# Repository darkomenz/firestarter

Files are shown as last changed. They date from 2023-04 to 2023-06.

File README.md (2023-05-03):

# Hexastorm PCB
This repository provides two modules;
 * **Laser module**  
    Contains six PCBs for the laser head. A box is created by the PCBs.  
    A baseboard, a front and back plate, a side plate and a top plate.  
    The laser module is standalone and can be controlled via SPI.  
 * **Main board**  
    The main board can be used to control motors and the laser head.  
    It's very basic and just serves as an example on how to control the laser head.   
    
A blog with progress updates is available on [Hackaday](https://hackaday.io/project/21933-open-hardware-fast-high-resolution-laser). 

# Status
Several systems were designed. A successful exposure is shown in this [video](https://youtu.be/dR09Tev0cPk).  
The current system is going through a complete iteration. Older versions of the laser head can be found in
the old branch of this repo.    
A presentation on the current target is found [here](https://youtu.be/b7ArZDhsyfI).  
Goals are;
  - improve documentation
  - make the laser module standalone

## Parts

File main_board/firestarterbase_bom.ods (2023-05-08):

Price | Qty | RefDes | Producer Part No | Producer | Farnell Part No | Mouser | DigiKey Part No | Description
1,63 | 1 |  | Wurth | 61304021821 | 2827916 |  |  | 40 pin connector
5,13 | 1 | U1 | ICE40UP5K-SG48I | Lattice |  | 842-ICE40UP5K-SG48I |  | ICE40UP5K FPGA, only mouser
0,752 | 2 | J1, J2 | 1-1734248-5 | TE Connectivity | 2890893 |  |  | connectors to scanhead and motor board
0,152 | 1 | D2 | CLMVC-FKA-CLBDGL7LBB79353 | Cree LED |  | 941-CLMVCFKACLBDGL7L |  | Color led
1,16 | 1 | J4 | MKDS 1,5/2 | Phoenix Contact | 3714240 |  |  | power connector
0,545 | 1 | U2 | MCP1700T-1202E/TT | Microchip | 1851940 |  |  | voltage supply 200 mA
0,745 | 1 | U5 | W25Q32JVSSIM | Winbond |  | 454-W25Q32JVSSIM |  | flash ram, Farnell alternative Is S25FL064LABMFI010
0,52 | 1 | Y1 | X1G0041710023 SG-210STF 13.56MHZ L | Epson | 2405713 |  |  | Oscillator, 2.5x2 mm 4 pins SMD, standaard formaat oscillators gaan snel uit vooruit
 | 1 |  | VISHAY | CRCW0805100RFKE | 1469862 (https://nl.farnell.com/vishay/crcw0805100rfkea/res-100r-1-0-125w-0805-thick-film/dp/1469862) |  |  | 100 ohm resistor
 | 4 |  | VISHAY | CRCW080510K0FKEA | 1469856 (https://nl.farnell.com/vishay/crcw080510k0fkea/res-10k-1-0-125w-0805-thick-film/dp/1469856) |  |  | 10K resistor
 | 5 |  | MULTICOMP | MC0805B104K101CT | 2320821 (https://nl.farnell.com/multicomp/mc0805b104k101ct/cap-0-1-f-100v-10-x7r-0805/dp/2320821) |  |  | 0.1 u cap (0.1 microfarad)
0,0906 | 5 |  | YAGEO | CC0805ZRY5V6BB475 | 3369339 (https://nl.farnell.com/yageo/cc0805zry5v6bb475/cap-4-7uf-10v-mlcc-0805/dp/3369339) |  |  | 4.7 u cap (4.7 microfarad)
0,401 | 2 | D8, D1 | ONSEMI | S1A | 9843868 (https://nl.farnell.com/fairchild-semiconductor/s1a/diode-standard-1a-50v-smd/dp/9843868) |  |  | diode
0,247 | 1 | F3 | Bel FUSE – Circuit protection | 0685T3000-01 | 2834856 (https://nl.farnell.com/bel-fuse-circuit-protection/0685t3000-01/fuse-smd-3a-slow-blow-1206/dp/2834856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) |  |  | fuse
Total | 12,888
Note
 |  |  | 691709710302 |  |  |  |  | 2 terminal block surface mount
1,94 | 1 | P1 | 95157-140LF | Amphenol ICC | 2751390 |  |  | WRONG NOT USED AS you need female, surface mount not used as it requires additional stencil and step!

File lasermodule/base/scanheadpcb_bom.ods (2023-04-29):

Price | Qty | RefDes | Producer | Producer Part No | Farnell Part No | Description
0,387 | 1 |  | Harwin | M20-9991045 | 1022259 | 2.54 header pin polygon motor, laserdiode, fan, power
0,616 | 2 | J3, J5 | Molex | 200528-0040 | 3500399 | photodiode 2x
0,453 | 1 | J2 | Amphenol ICC | SFW15R-2STE1LF | 2890893 | FFC / FPC Board Connector, 1 mm, 15 Contacts, Receptacle, FCI 58RF SFW-R series, Surface Mount
1,6 | 1 | U1 | MAXIM | MAX5395MATA+T | 2763348 (https://nl.farnell.com/maxim-integrated-products/max5395mata-t/digital-pot-volatile-50-k-tdfn/dp/2763348) | Digipot 50 kohm
0,0883 | 3 | R1, R2, R3, R4 | VISHAY | CRCW080510K0FKEA | 1469856 (https://nl.farnell.com/vishay/crcw080510k0fkea/res-10k-1-0-125w-0805-thick-film/dp/1469856) | resistor 10 Kohm
0,128 | 1 | C4 | MULTICOMP | MC0805B104K101CT | 2320821 (https://nl.farnell.com/multicomp/mc0805b104k101ct/cap-0-1-f-100v-10-x7r-0805/dp/2320821) | 0.1 µF 2012 cap
0,0725 | 1 | C1 | AVX | 08055C472KAT2A | 499213 (https://nl.farnell.com/avx/08055c472kat2a/cap-4700pf-50v-10-x7r-0805/dp/499213) | 47 nF 2012 cap
0,28 | 2 | C2, C3, C5, C6, C7 | AVX | 08055C105KAT2A | 2094043 (https://nl.farnell.com/avx/08055c105kat2a/cap-1-f-50v-10-x7r-0805/dp/2094043) | 1 µF 2012 cap
7 | 1 | U2 | IC HOUSE | IC-HKB-S08-TP |  | laserdriver only sold via resellers (AVE)
0,714 | 1 | Q1 | INFINEON | IRFML8244TRPBF | 1857298 (http://www.farnell.com/datasheets/1911843.pdf) | MOSFET fan
0,105 | 1 | D1 | ON SEMICONDUCTOR | S1A | 9843868 (https://nl.farnell.com/fairchild-semiconductor/s1a/diode-standard-1a-50v-smd/dp/9843868) | flyback diode fan
1,53 | 1 | U3 | ON SEMICONDUCTOR | NCD98010XMXTAG | 3463948 | ADC converter SPI
1,14 | 3 | F1, F2, F3 | Bel Fuse – Circuit Protection | 0685T3000-01 | 2834856
2,19 | 1 |  | ABL Heatsinks | BGA-STD-015 | 2084425 | heatsink laser diode driver
0,248 | 1 | J1 | Molex | 22-23-2031 | 1462950 | power connector
Total | 19,9044
Cables
0,95 | 1 |  |  | Link (https://elektronicavoorjou.nl/product/jumper-wire-5-pins-10cm/) |  | Jumper wire 5 pin Mirror motor connect
0,95 | 2 |  |  | Link (https://elektronicavoorjou.nl/product/jumper-wire-2-pins-10cm/) |  | Jumper wire 2 pin Laserdiode + Fan
 |  |  |  |  |  | Molex cable for power, crimp, connector
1,03 | 1 |  |  | MP-FFCA10041003A | 3385294 | FFC 4P aansluiting 2 photodiodes
4 | 1 |  |  | Link (https://www.tinytronics.nl/shop/nl/kabels-en-connectoren/kabels-en-adapters/ffc/raspberry-pi-camerakabel-15-pin-fpc-flex-100cm) | 3527203 | FFC 15P data cable 1 meter, cheap as it compatible raspberry
Panasonic Motor connector
Connector |  |  | TE Connectivity AMP Connectors | 292171-5 | A98794-ND
header |  |  | TE Connectivity | 6-173977-5 | 571-6-173977-5
cable clamp |  |  | TE Connectivity | 179227-4 | 571-179227-4
NBC3111 Motor connector |  |  |  |  |  | Original for sharp AR160 161 200 168 1818 158 2820 2718 Polygon Mirror Motor, store name Printer Accessories Store, brand name : HLKTKT
connector |  |  | TE Connectivity AMP Connectors | 292173-5 |  | connector present on board
insert |  |  |  | 179228-5 |  | amp termination for inserts
wire insert for insert |  |  |  | 179227-1 |  | contact end wire depends on AWG
clamp for wire insert for insert |  |  |  | 2305570-1 |  | crimp tool

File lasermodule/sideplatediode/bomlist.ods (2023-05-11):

Price | Qty | RefDes | Producer Part No | Farnell Part | Description
0,0177 | 3 | R1, R3, R6 | CRCW080522K0FKEA | 1469896 (https://nl.farnell.com/vishay/crcw080522k0fkea/res-22k-1-0-125w-0805-thick-film/dp/1469896?st=CRCW080522K0FKEA) | smd resisitor
0,0094 | 5 | R2, R4, R5, R7, R8 | MCWR08X8201FTL | 2447732 (https://nl.farnell.com/multicomp/mcwr08x8201ftl/res-8k2-1-0-125w-thick-film/dp/2447732) | smd resisitor
0,08 | 1 | R7 | CRCW12061K50FKEAHP | 1739015 (http://www.farnell.com/datasheets/2618455.pdf) | smd resisitor
0,413 | 2 | U1, U2 |  | 2920854 (https://nl.farnell.com/microchip/mic920yc5-tr/opamp-80mhz-40-to-85deg-c/dp/2920854) | operational amplifier
1,59 | 1 | D1 | SFH 2440 | 2981709 | photodiode
0,279 | 1 | C3 | 08055C105KAT2A | 2094043 (http://www.farnell.com/datasheets/2237835.pdf) | 1 µF 2012 cap buffer, not sure if 2 are needed copied from previous board
0,0759 | 1 | C1 | MC0805B221K500CT | 1759208 (https://nl.farnell.com/multicomp/mc0805b221k500ct/cap-220pf-50v-10-x7r-0805/dp/1759208) | 220 pF 2012 cap used in opamp
0,616 | 1 | J1 | 200528-0040 | 3500399 | photodiode connector
Total | 3,567
Alternative photodiode
BPW 34 BS-Z
 |  |  | 929974-01-36-RK | 2064805 | 36 way THH connector 2.54 mm

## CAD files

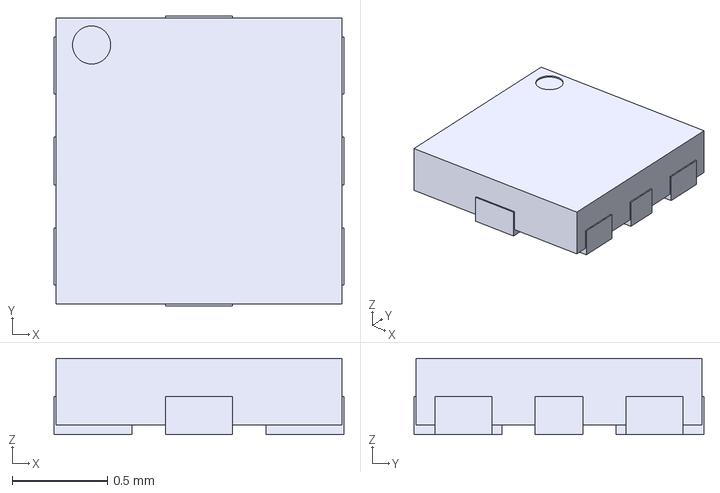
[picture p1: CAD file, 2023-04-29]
lasermodule/base/comp/eec.models/Texas_Instruments_-_ADS7040IRUGR.step
1.52 x 1.52 x 0.4 mm

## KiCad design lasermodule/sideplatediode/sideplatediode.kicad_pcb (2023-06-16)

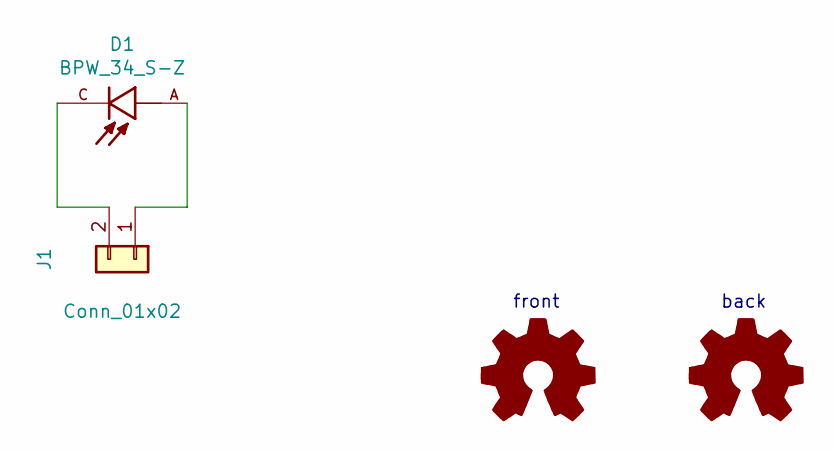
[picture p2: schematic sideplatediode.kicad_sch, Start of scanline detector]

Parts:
D1: BPW_34_S-Z; DIO_BPW_34_S-Z; PARTREV 1.5
J1: Conn_01x02; PinHeader_1x02_P2.54mm_Horizontal
L1, L2: Logo_Open_Hardware_Small; hexastorm

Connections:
unnamed: D1.A, J1.1
unnamed: D1.C, J1.2

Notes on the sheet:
back
front

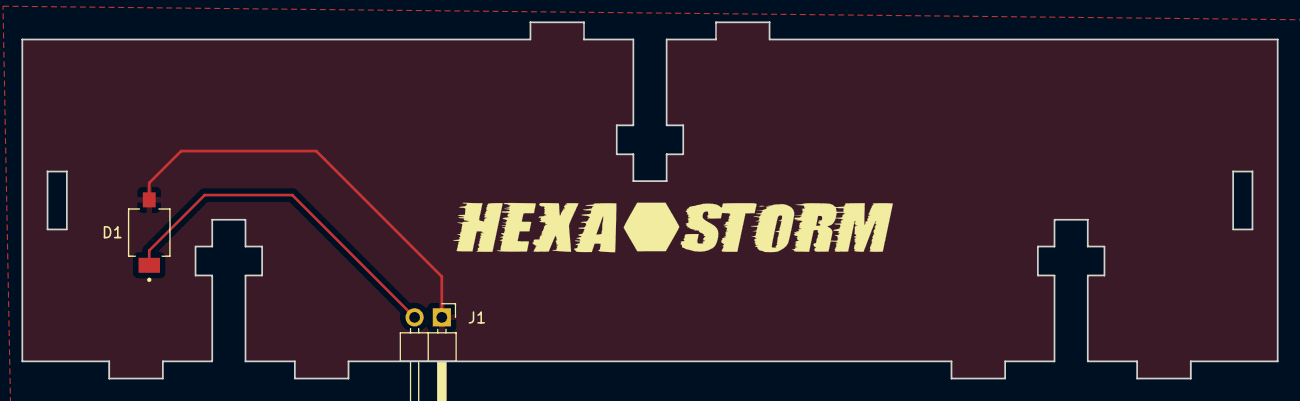
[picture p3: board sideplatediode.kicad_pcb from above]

Board: 2 copper layers, 117.0 x 33.2 mm, 4 parts (1 on the bottom side), 2 nets.

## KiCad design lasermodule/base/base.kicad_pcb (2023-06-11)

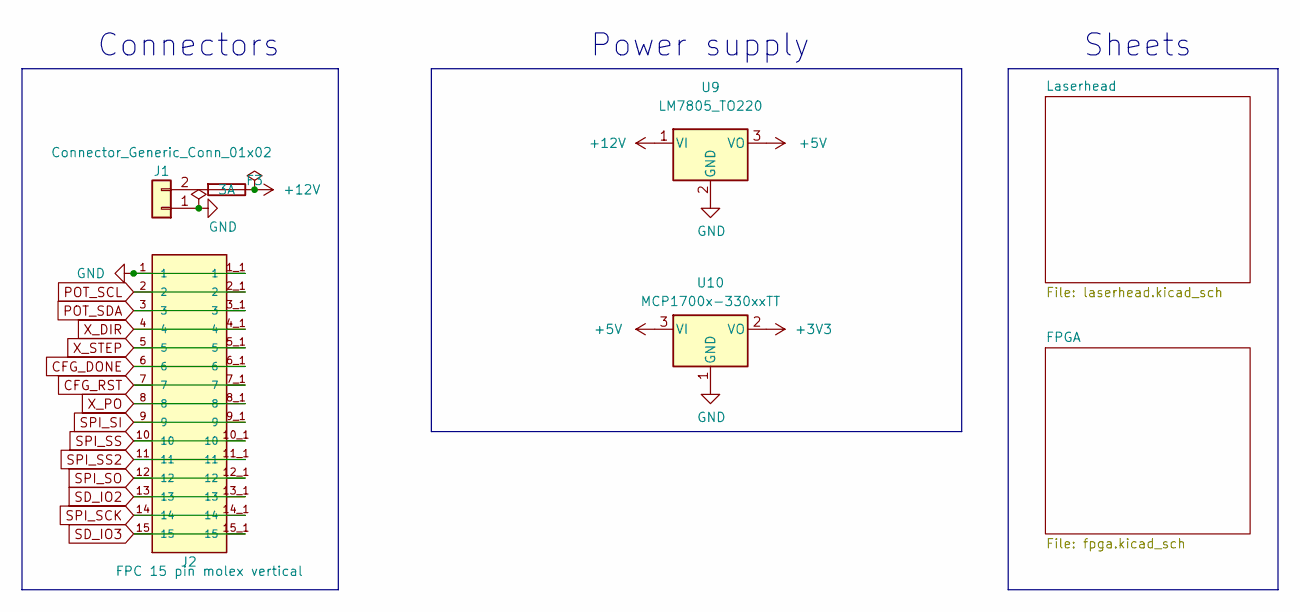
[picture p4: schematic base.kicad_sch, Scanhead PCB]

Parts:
F3: 3A; Fuse_1206_3216Metric
J1: Connector_Generic_Conn_01x02; AMASS_XT30PW-F_1x02_P2.50mm_Horizontal
J2: FPC 15 pin molex vertical; TE_1-1734248-5; PARTREV E1
U9: LM7805_TO220; TO-220-3_Vertical
U10: MCP1700x-330xxTT; SOT-23

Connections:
+3V3: U10.2 (VO); also elsewhere on the board
+5V: U9.3 (VO), U10.3 (VI); also elsewhere on the board
+12V: F3.1, U9.1 (VI); also elsewhere on the board
CFG_DONE: J2.6, J2.6_1 (6); also elsewhere on the board
CFG_RST: J2.7, J2.7_1 (7); also elsewhere on the board
GND: J1.1, J2.1, J2.1_1 (1), U9.2 (GND), U10.1 (GND); also elsewhere on the board
unnamed: F3.2, J1.2
POT_SCL: J2.2, J2.2_1 (2); also elsewhere on the board
POT_SDA: J2.3, J2.3_1 (3); also elsewhere on the board
SD_IO2: J2.13, J2.13_1 (13); also elsewhere on the board
SD_IO3: J2.15, J2.15_1 (15); also elsewhere on the board
SPI_SCK: J2.14, J2.14_1 (14); also elsewhere on the board
SPI_SI: J2.9, J2.9_1 (9); also elsewhere on the board
SPI_SO: J2.12, J2.12_1 (12); also elsewhere on the board
SPI_SS: J2.10, J2.10_1 (10); also elsewhere on the board
SPI_SS2: J2.11, J2.11_1 (11); also elsewhere on the board
X_DIR: J2.4, J2.4_1 (4); also elsewhere on the board
X_PO: J2.8, J2.8_1 (8); also elsewhere on the board
X_STEP: J2.5, J2.5_1 (5); also elsewhere on the board

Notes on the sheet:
Power supply
Connectors
Sheets

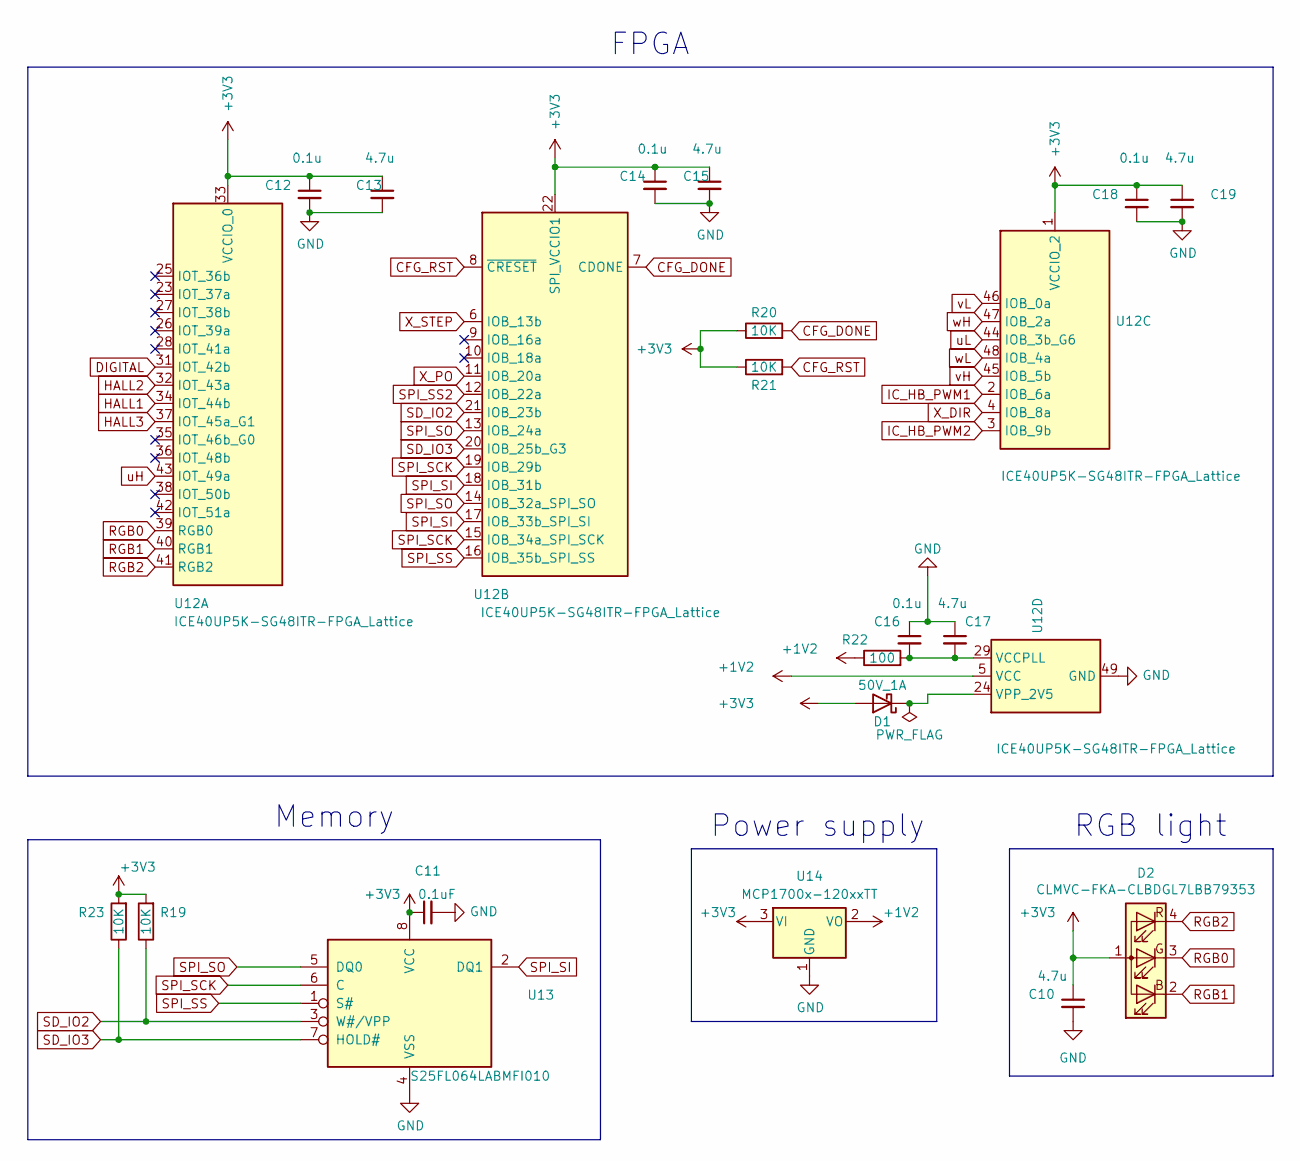
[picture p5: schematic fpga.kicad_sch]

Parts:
C10, C13, C15, C17, C19: 4.7u; C_0805_2012Metric_Pad1.18x1.45mm_HandSolder
C11: 0.1uF; C_0805_2012Metric_Pad1.18x1.45mm_HandSolder
C12, C14, C16, C18: 0.1u; C_0805_2012Metric_Pad1.18x1.45mm_HandSolder
D1: 50V_1A; D_SMA_Handsoldering
D2: CLMVC-FKA-CLBDGL7LBB79353; LED_Cree-PLCC4_2x2mm_CW
R19, R20, R21, R23: 10K; R_0805_2012Metric_Pad1.20x1.40mm_HandSolder
R22: 100; R_0805_2012Metric_Pad1.20x1.40mm_HandSolder
U12: ICE40UP5K-SG48ITR-FPGA_Lattice; QFN-48-1EP_7x7mm_P0.5mm_EP5.6x5.6mm
U13: S25FL064LABMFI010; SOIC-8W_5.3x5.3mm_P1.27mm
U14: MCP1700x-120xxTT; SOT-23

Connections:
+1V2: R22.1, U12.5 (VCC), U12.30 (VCC), U14.2 (VO)
+3V3: C10.1, C11.1, C12.1, C13.1, C14.1, C15.1, C18.1, C19.1, D1.2 (A), D2.1 (A), R19.2, R20.1, R21.1, R23.2, U12.1 (VCCIO_2), U12.22 (SPI_VCCIO1), U12.33 (VCCIO_0), U13.8 (VCC), U14.3 (VI); also elsewhere on the board
CFG_DONE: R20.2, U12.7 (CDONE); also elsewhere on the board
CFG_RST: R21.2, U12.8 (~CRESET); also elsewhere on the board
DIGITAL: U12.31 (IOT_42b); also elsewhere on the board
GND: C10.2, C11.2, C12.2, C13.2, C14.2, C15.2, C16.1, C17.1, C18.2, C19.2, U12.49 (GND), U13.4 (VSS), U14.1 (GND); also elsewhere on the board
HALL1: U12.34 (IOT_44b); also elsewhere on the board
HALL2: U12.32 (IOT_43a); also elsewhere on the board
HALL3: U12.37 (IOT_45a_G1); also elsewhere on the board
IC_HB_PWM1: U12.2 (IOB_6a); also elsewhere on the board
IC_HB_PWM2: U12.3 (IOB_9b); also elsewhere on the board
unnamed: D1.1 (K), U12.24 (VPP_2V5)
unnamed: C16.2, C17.2, R22.2, U12.29 (VCCPLL)
RGB0: D2.3 (GK), U12.39 (RGB0)
RGB1: D2.2 (RK), U12.40 (RGB1)
RGB2: D2.4 (BK), U12.41 (RGB2)
SD_IO2: R19.1, U12.21 (IOB_23b), U13.3 (W#/VPP); also elsewhere on the board
SD_IO3: R23.1, U12.20 (IOB_25b_G3), U13.7 (HOLD#); also elsewhere on the board
SPI_SCK: U12.15 (IOB_34a_SPI_SCK), U12.19 (IOB_29b), U13.6 (C); also elsewhere on the board
SPI_SI: U12.17 (IOB_33b_SPI_SI), U12.18 (IOB_31b), U13.2 (DQ1); also elsewhere on the board
SPI_SO: U12.13 (IOB_24a), U12.14 (IOB_32a_SPI_SO), U13.5 (DQ0); also elsewhere on the board
SPI_SS: U12.16 (IOB_35b_SPI_SS), U13.1 (S#); also elsewhere on the board
SPI_SS2: U12.12 (IOB_22a); also elsewhere on the board
X_DIR: U12.4 (IOB_8a); also elsewhere on the board
X_PO: U12.11 (IOB_20a); also elsewhere on the board
X_STEP: U12.6 (IOB_13b); also elsewhere on the board
uH: U12.43 (IOT_49a); also elsewhere on the board
uL: U12.44 (IOB_3b_G6); also elsewhere on the board
vH: U12.45 (IOB_5b); also elsewhere on the board
vL: U12.46 (IOB_0a); also elsewhere on the board
wH: U12.47 (IOB_2a); also elsewhere on the board
wL: U12.48 (IOB_4a); also elsewhere on the board

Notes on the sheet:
Power supply
FPGA
RGB light
Memory

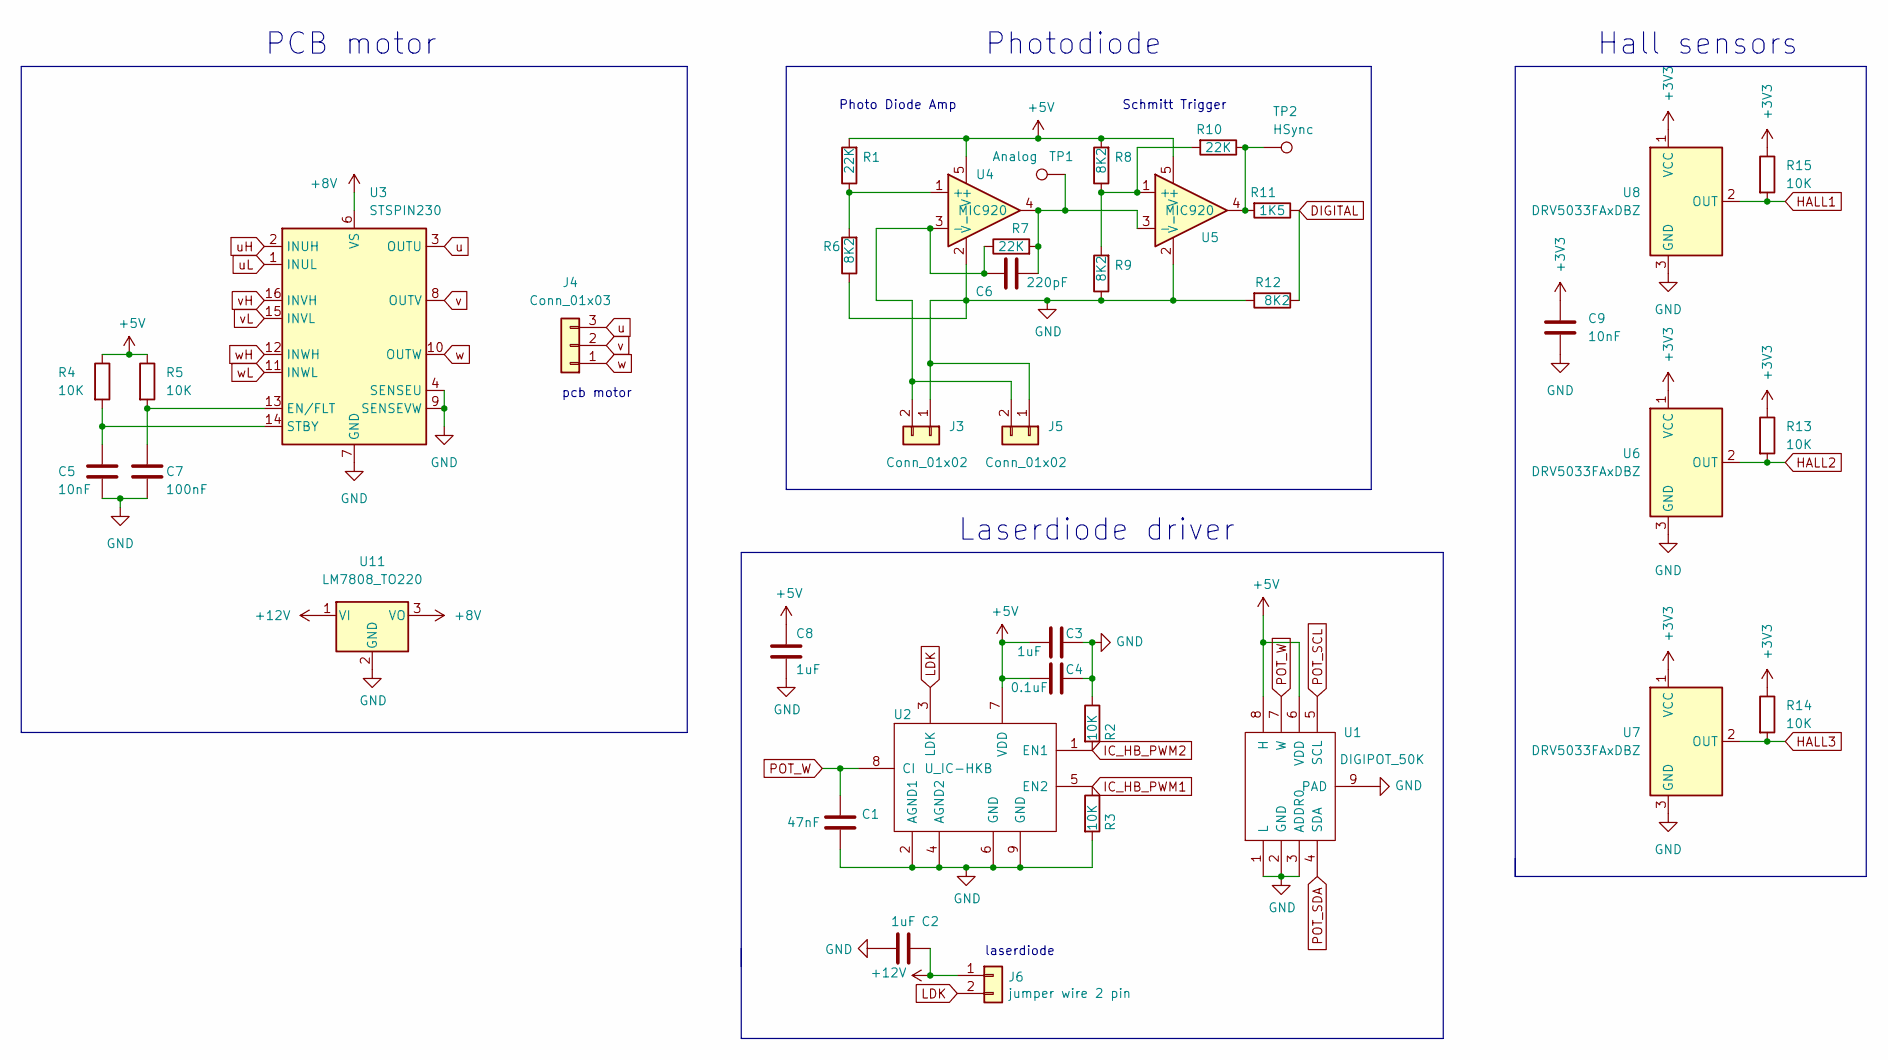
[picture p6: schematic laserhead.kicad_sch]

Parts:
C1: 47nF; C_0805_2012Metric_Pad1.18x1.45mm_HandSolder
C2, C3, C8: 1uF; C_0805_2012Metric_Pad1.18x1.45mm_HandSolder
C4: 0.1uF; C_0805_2012Metric_Pad1.18x1.45mm_HandSolder
C5, C9: 10nF; C_0805_2012Metric_Pad1.18x1.45mm_HandSolder
C6: 220pF; C_0805_2012Metric_Pad1.18x1.45mm_HandSolder
C7: 100nF; C_0805_2012Metric_Pad1.18x1.45mm_HandSolder
J3, J5: Conn_01x02; PinHeader_1x02_P2.54mm_Vertical
J4: Conn_01x03; pcbmotor_smd
J6: jumper wire 2 pin; Molex_KK-254_AE-6410-02A_1x02_P2.54mm_Vertical
R1, R7, R10: 22K; R_0805_2012Metric_Pad1.20x1.40mm_HandSolder
R2, R3, R4, R5, R13, R14, R15: 10K; R_0805_2012Metric_Pad1.20x1.40mm_HandSolder
R6, R8, R9, R12: 8K2; R_0805_2012Metric_Pad1.20x1.40mm_HandSolder
R11: 1K5; R_0805_2012Metric_Pad1.20x1.40mm_HandSolder
TP1: Analog; TestPoint_Pad_D1.0mm
TP2: HSync; TestPoint_Pad_D1.0mm
U1: DIGIPOT_50K; TDFN-8-1EP
U2: U_IC-HKB; ICHKB
U3: STSPIN230; VQFN-16-1EP_3x3mm_P0.5mm_EP1.8x1.8mm
U4, U5: MIC920; SOT-353_SC-70-5_Handsoldering
U6, U7, U8: DRV5033FAxDBZ; SOT-23
U11: LM7808_TO220; TO-220-3_Vertical

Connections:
+3V3: C9.1, R13.1, R14.1, R15.1, U6.1 (VCC), U7.1 (VCC), U8.1 (VCC); also elsewhere on the board
+5V: C3.2, C4.2, C8.1, R1.2, R4.1, R5.1, R8.2, U1.6 (VDD), U1.8 (H), U2.7 (VDD), U4.5 (V+), U5.5 (V+); also elsewhere on the board
+8V: U3.6 (VS), U11.3 (VO)
+12V: C2.2, J6.1, U11.1 (VI); also elsewhere on the board
DIGITAL: R11.1, R12.1; also elsewhere on the board
GND: C1.1, C2.1, C3.1, C4.1, C5.2, C7.2, C8.2, C9.2, J3.1, J5.1, R2.1, R3.2, R6.1, R9.1, R12.2, U1.1 (L), U1.2 (GND), U1.3 (ADDR0), U1.9 (PAD), U2.2 (AGND1), U2.4 (AGND2), U2.6 (GND), U2.9 (GND), U3.4 (SENSEU), U3.7 (GND), U3.9 (SENSEVW), U3.17 (GND), U4.2 (V-), U5.2 (V-), U6.3 (GND), U7.3 (GND), U8.3 (GND), U11.2 (GND); also elsewhere on the board
HALL1: R15.2, U8.2 (OUT); also elsewhere on the board
HALL2: R13.2, U6.2 (OUT); also elsewhere on the board
HALL3: R14.2, U7.2 (OUT); also elsewhere on the board
IC_HB_PWM1: R3.1, U2.5 (EN2); also elsewhere on the board
IC_HB_PWM2: R2.2, U2.1 (EN1); also elsewhere on the board
LDK: J6.2, U2.3 (LDK)
unnamed: C6.2, J3.2, J5.2, R7.1, U4.3 (-)
unnamed: R10.1, R11.2, TP2.1, U5.4
unnamed: C7.1, R5.2, U3.13 (EN/FLT)
unnamed: C5.1, R4.2, U3.14 (STBY)
unnamed: R1.1, R6.2, U4.1 (+)
unnamed: R8.1, R9.2, R10.2, U5.1 (+)
unnamed: C6.1, R7.2, TP1.1, U4.4, U5.3 (-)
POT_SCL: U1.5 (SCL); also elsewhere on the board
POT_SDA: U1.4 (SDA); also elsewhere on the board
POT_W: C1.2, U1.7 (W), U2.8 (CI)
u: J4.3, U3.3 (OUTU)
uH: U3.2 (INUH); also elsewhere on the board
uL: U3.1 (INUL); also elsewhere on the board
v: J4.2, U3.8 (OUTV)
vH: U3.16 (INVH); also elsewhere on the board
vL: U3.15 (INVL); also elsewhere on the board
w: J4.1, U3.10 (OUTW)
wH: U3.12 (INWH); also elsewhere on the board
wL: U3.11 (INWL); also elsewhere on the board

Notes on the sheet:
pcb motor
Photo Diode Amp
Laserdiode driver
Schmitt Trigger
laserdiode
PCB motor
Photodiode
Hall sensors

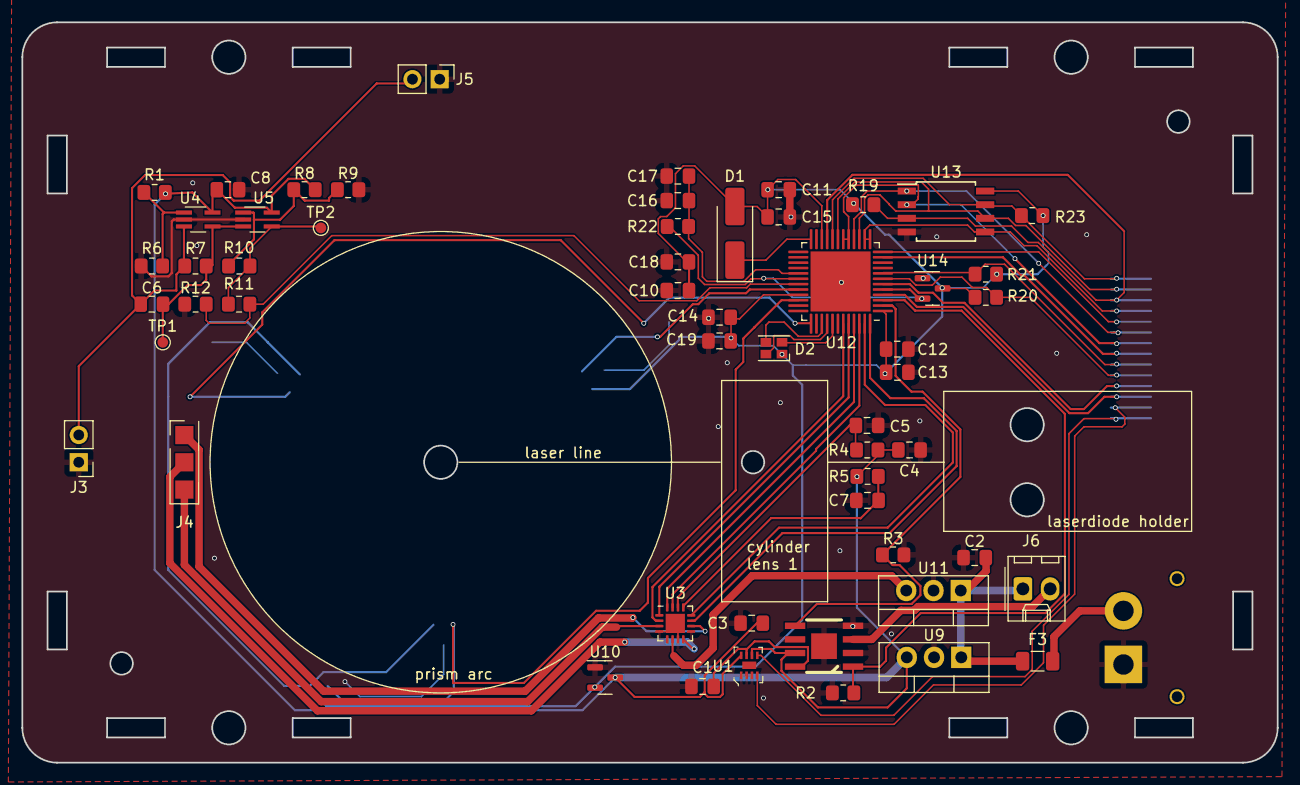
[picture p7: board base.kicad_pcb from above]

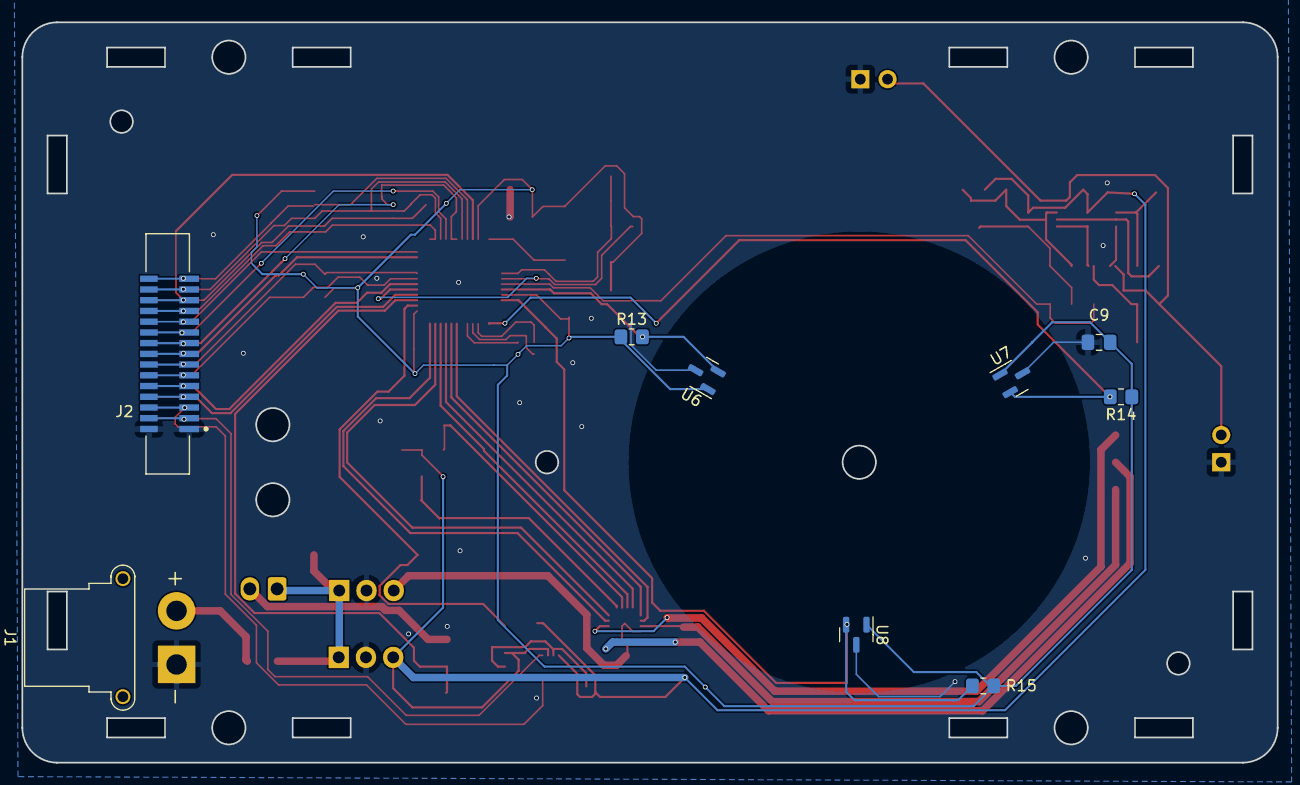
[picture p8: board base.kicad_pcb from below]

Board: 2 copper layers, 117.0 x 69.0 mm, 64 parts (9 on the bottom side), 50 nets.

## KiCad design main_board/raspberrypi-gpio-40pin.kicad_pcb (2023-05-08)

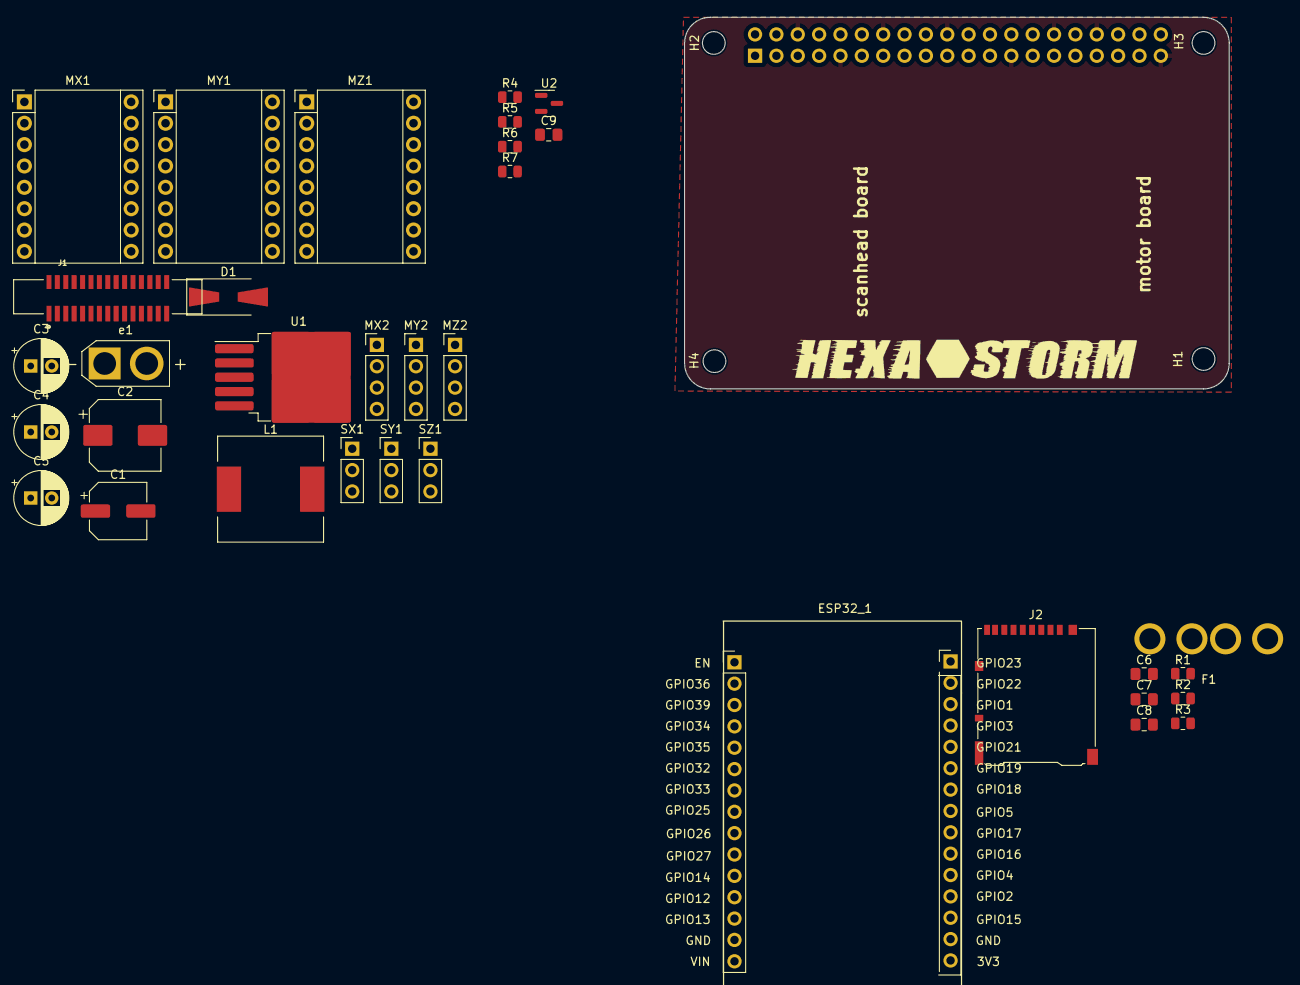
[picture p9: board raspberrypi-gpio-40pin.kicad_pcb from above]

Board: 2 copper layers, 64.8 x 44.2 mm, 40 parts (1 on the bottom side), 48 nets, no tracks yet.

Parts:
C1: 330 uF; CP_Elec_6.3x7.7
C2: 220 uF; CP_Elec_8x10
C3, C4, C5: 100uF; CP_Radial_D6.3mm_P2.50mm
C6, C7, C8: 0.1uF; C_0805_2012Metric_Pad1.18x1.45mm_HandSolder
C9: 0.1U; C_0805_2012Metric_Pad1.18x1.45mm_HandSolder
D1: SS320-HF; D_SMA-SMB_Universal_Handsoldering
ESP32_1: ESP32_Devkit_DOIT_V1
F1: 30A; MCCQ-121
G1: hexastorm
H1, H2, H3, H4: MountingHole; MountingHole_2.7mm_M2.5
J1: 1-1734248-5; TE_1-1734248-5
J2: Micro_SD_Card_Det_Hirose_DM3AT; microSD_HC_Hirose_DM3AT-SF-PEJM5
L1: 33 uH; L_12x12mm_H6mm
MX1: X_STEPPER; TMC2130
MX2: MOLEX_2041; PinHeader_1x04_P2.54mm_Vertical
MY1: Y_STEPPER; TMC2130
MY2: MOLEX_2041; PinHeader_1x04_P2.54mm_Vertical
MZ1: Z_STEPPER; TMC2130
MZ2: MOLEX_2041; PinHeader_1x04_P2.54mm_Vertical
P1: Conn_02x20_Odd_Even; PinSocket_2x20_P2.54mm_Vertical
R1, R2, R3, R4, R5, R6, R7: 10K; R_0805_2012Metric
SX1: MOLEX_2031; PinHeader_1x03_P2.54mm_Vertical
SY1: MOLEX_2031; PinHeader_1x03_P2.54mm_Vertical
SZ1: MOLEX_2031; PinHeader_1x03_P2.54mm_Vertical
U1: LM2596S-5; TO-263-5_TabPin3
U2: MCP1700x-330xxTT; SOT-23
e1: Screw_Terminal_01x02; AMASS_XT30U-F_1x02_P5.0mm_Vertical

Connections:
+3.3V: C9.1, ESP32_1.16 (3V3), J2.4 (VDD), MX1.10 (VDD), MY1.10 (VDD), MZ1.10 (VDD), P1.1, P1.17, R1.1, R2.1, R3.1, R4.2, R5.1, R6.1, R7.2, SX1.1, SY1.1, SZ1.1, U2.2 (VO)
+5V: C2.1, ESP32_1.15 (VIN), L1.2, P1.2, P1.4, U1.4 (FB), U2.3 (VI)
+12V: C1.1, C3.2, C4.2, C5.2, F1.3, F1.4, MX1.16 (VMOT), MY1.16 (VMOT), MZ1.16 (VMOT), U1.1 (VIN)
CFG_DONE: ESP32_1.7 (GPIO33), J1.6, J1.6_1 (6), P1.29
CFG_RST: ESP32_1.28 (GPIO1), J1.7, J1.7_1 (7), P1.37
ENABLE: ESP32_1.27 (GPIO3), MX1.1 (~EN), MY1.1 (~EN), MZ1.1 (~EN), P1.11
GND: C1.2, C2.2, C3.1, C4.1, C5.1, C6.1, C7.1, C8.1, C9.2, D1.2 (A), ESP32_1.14 (GND), ESP32_1.17 (GND), J1.1, J1.1_1 (1), J2.6 (VSS), J2.11 (SHIELD), MX1.9 (GND), MX1.15 (GND), MY1.9 (GND), MY1.15 (GND), MZ1.9 (GND), MZ1.15 (GND), P1.6, P1.9, P1.14, P1.20, P1.25, P1.30, P1.34, P1.39, SX1.3, SY1.3, SZ1.3, U1.3 (GND), U1.5 (~ON/OFF), U2.1 (GND), e1.1
unnamed: D1.1 (K), L1.1, U1.2 (OUT)
unnamed: J2.8 (DAT1), R7.1
unnamed: J2.1 (DAT2), R6.2
unnamed: F1.1, F1.2, e1.2
POT_SCL: ESP32_1.29 (GPIO22), J1.2, J1.2_1 (2), P1.5
POT_SDA: ESP32_1.26 (GPIO21), J1.3, J1.3_1 (3), P1.3
SD_CLK: ESP32_1.24 (GPIO18), J2.5 (CLK)
SD_IO2: ESP32_1.4 (GPIO34), J1.13, J1.13_1 (13), P1.18
SD_IO3: ESP32_1.5 (GPIO35), J1.15, J1.15_1 (15), P1.22
SD_MISO: ESP32_1.25 (GPIO19), J2.7 (DAT0), R4.1
SD_MOSI: ESP32_1.30 (GPIO23), J2.3 (CMD), R5.2
SD_SS: ESP32_1.23 (GPIO5), J2.2 (DAT3/CD)
SPI_SCK: ESP32_1.6 (GPIO32), J1.14, J1.14_1 (14), MX1.3 (SCK), MY1.3 (SCK), MZ1.3 (SCK), P1.40
SPI_SI: ESP32_1.9 (GPIO26), J1.9, J1.9_1 (9), MX1.2 (SDI), P1.38
SPI_SO: ESP32_1.8 (GPIO25), J1.12, J1.12_1 (12), MZ1.5 (SDO), P1.35
SPI_SS: ESP32_1.10 (GPIO27), J1.10, J1.10_1 (10), MZ1.4 (CS), P1.24
SPI_SS2: J1.11, J1.11_1 (11), P1.36
SPI_SS3: ESP32_1.22 (GPIO17), MX1.4 (CS), MY1.4 (CS), P1.26
SPI_XOYI: MX1.5 (SDO), MY1.2 (SDI)
SPI_YOZI: MY1.5 (SDO), MZ1.2 (SDI)
X_1A: MX1.12 (M1A), MX2.3
X_1B: MX1.11 (M1B), MX2.4
X_2A: MX1.13 (M2A), MX2.2
X_2B: MX1.14 (M2B), MX2.1
X_DIR: J1.4, J1.4_1 (4), MX1.8 (DIR)
X_PO: C6.2, J1.8, J1.8_1 (8), R1.2, SX1.2
X_STEP: J1.5, J1.5_1 (5), MX1.7 (STEP)
Y_1A: MY1.12 (M1A), MY2.3
Y_1B: MY1.11 (M1B), MY2.4
Y_2A: MY1.13 (M2A), MY2.2
Y_2B: MY1.14 (M2B), MY2.1
Y_DIR: ESP32_1.13 (GPIO13), MY1.8 (DIR), P1.10
Y_PO: C7.2, ESP32_1.21 (GPIO16), P1.12, R2.2, SY1.2
Y_STEP: ESP32_1.12 (GPIO12), MY1.7 (STEP), P1.8
Z_1A: MZ1.12 (M1A), MZ2.3
Z_1B: MZ1.11 (M1B), MZ2.4
Z_2A: MZ1.13 (M2A), MZ2.2
Z_2B: MZ1.14 (M2B), MZ2.1
Z_DIR: ESP32_1.3 (GPIO39), MZ1.8 (DIR), P1.21
Z_PO: C8.2, ESP32_1.11 (GPIO14), P1.23, R3.2, SZ1.2
Z_STEP: ESP32_1.2 (GPIO36), MZ1.7 (STEP), P1.19

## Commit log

2023-04-29 cleaned up repo for new design cycle
    [5022311500.stp, BeagleBone-Black-Cape.kicad_pcb, BeagleBone-Black-Cape.sch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]
2023-05-03 laid out board
    [fpga.kicad_sch, laserhead.kicad_sch, scanhead_pcb.kicad_sch]
2023-05-08 finished schema for main
    [esp32.kicad_sch, firestarterbase_bom.ods, raspberrypi-gpio-40pin.kicad_pcb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]
2023-05-09 added pcbmotor, renamed some folders
    [Texas_Instruments_-_ADS7040IRUGR.step, base.kicad_pcb, base.kicad_sch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]
2023-05-09 removed motor
2023-05-11 further cleaned up and tested renders in blender
    [base.kicad_pcb, base.kicad_sch, fpga.kicad_sch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]
2023-05-11 started adding other plates
    [backplate.kicad_pcb, backplate.kicad_sch, backplate.sch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]
2023-06-06 synced latest changes
    [pcbmotor.kicad_pcb]
2023-06-10 simplified loading in freecad, updated pcbs
    [backplate.kicad_pcb, backplate.kicad_sch, backplate.sch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]
2023-06-11 pcbs can be rendered
    [backplate.kicad_pcb, base.kicad_pcb, frontplate.kicad_pcb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]
2023-06-16 changed position logos
    [backplate.kicad_pcb, frontplate.kicad_pcb, sideplate.kicad_pcb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]
